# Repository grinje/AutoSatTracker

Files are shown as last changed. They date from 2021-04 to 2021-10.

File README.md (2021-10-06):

# AutoSatTracker-ESP32
Tracking satellites with custom hardware based on stepper motors. A blog description of the project can be found at https://www.la3t.no/automatic-satellite-tracker/

The construction of the rotator is based on the SatNOGS project found here: https://gitlab.com/librespacefoundation/satnogs/satnogs-rotator/tree/master

The controller is based on the work by Elwood Downey found here: http://clearskyinstitute.com/ham/AST/. 
The software is based on this repo by Bjoern Kerler: https://github.com/bkerler/AutoSatTracker-ESP

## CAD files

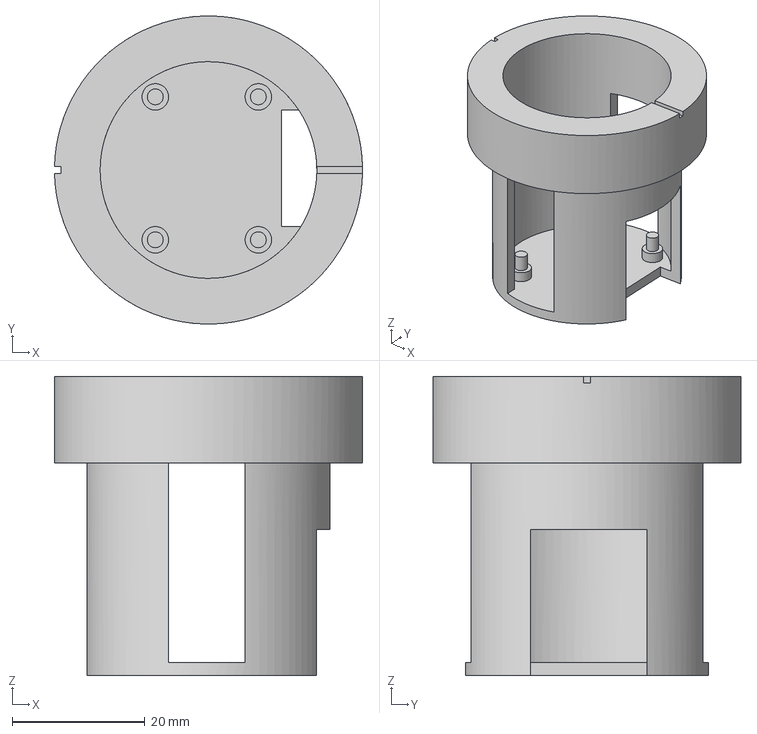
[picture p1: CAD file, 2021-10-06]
Fusion360-CADfiles/CompassHolder v4.3mf
46.3 x 46.3 x 45.0 mm

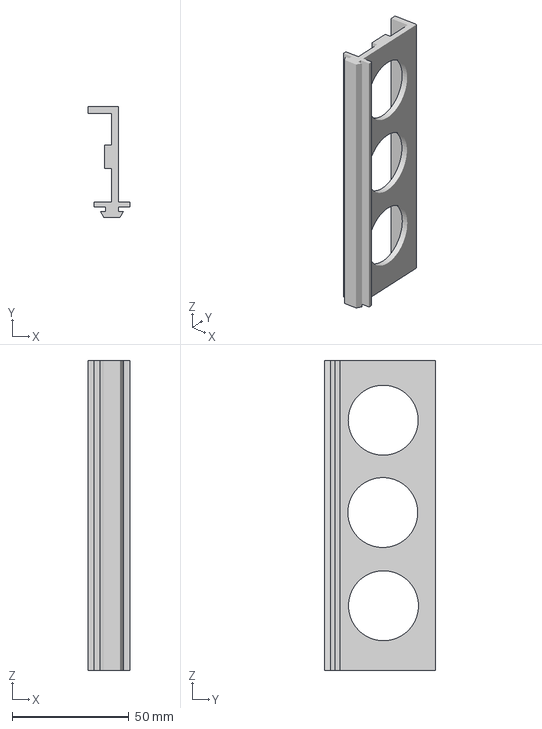
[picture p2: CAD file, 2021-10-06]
Fusion360-CADfiles/Battery Holder v2.3mf
18.0 x 47.5 x 133.0 mm

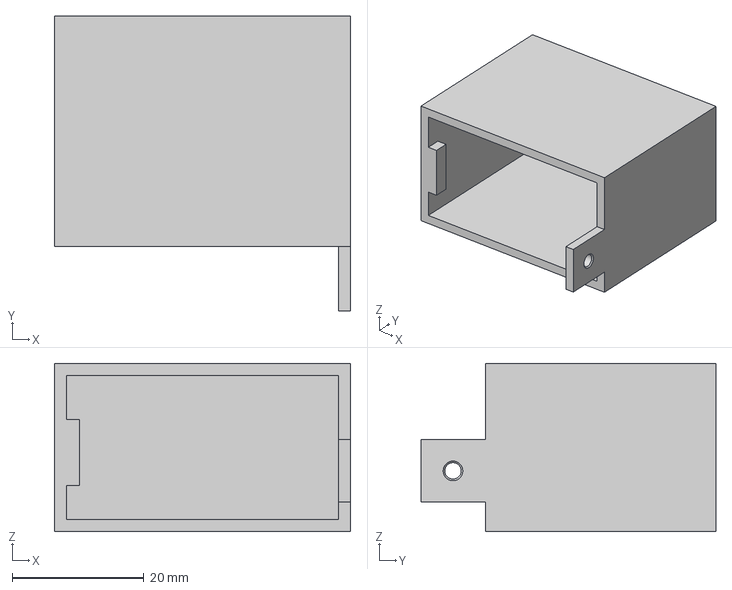
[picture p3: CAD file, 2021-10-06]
Fusion360-CADfiles/Antenna-mount Cap v8.3mf
45.0 x 44.8 x 25.6 mm

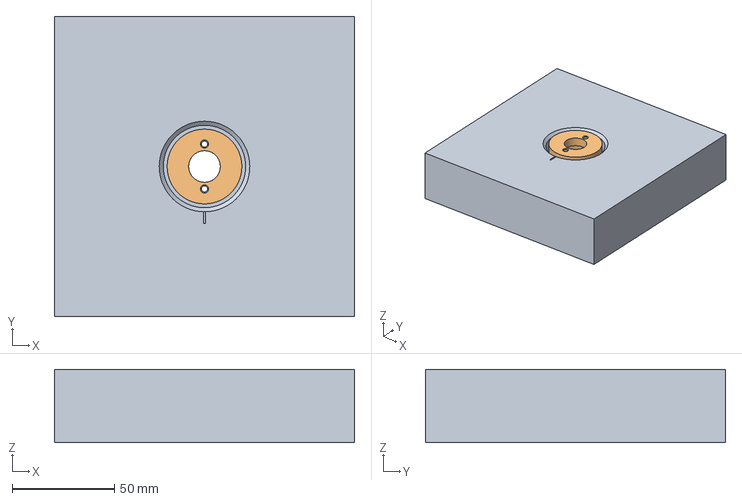
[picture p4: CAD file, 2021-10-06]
Fusion360-CADfiles/TopCover v3.3mf
147.0 x 147.0 x 36.0 mm

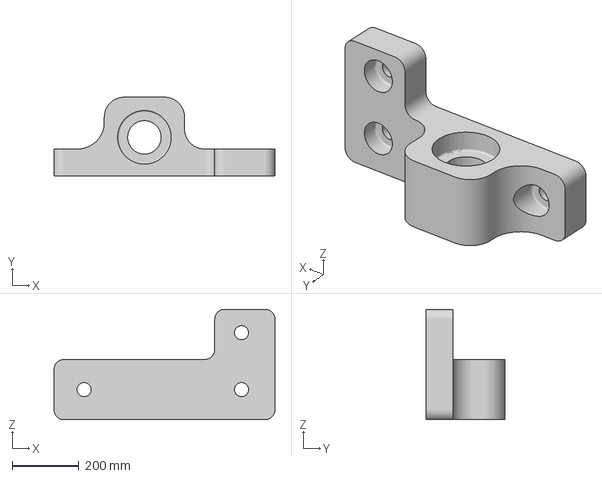
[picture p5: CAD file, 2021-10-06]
Fusion360-CADfiles/C1061-5-GIJ v2.3mf
660.0 x 235.0 x 330.0 mm

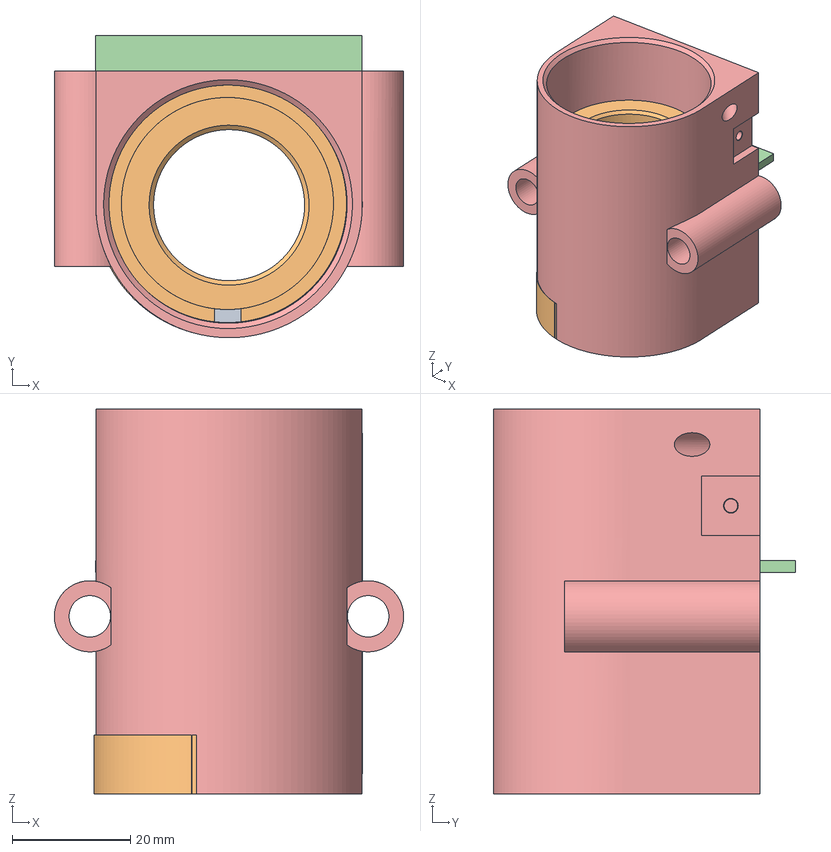
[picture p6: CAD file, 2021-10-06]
Fusion360-CADfiles/Antenna-mount v8.3mf
59.0 x 51.1 x 65.0 mm

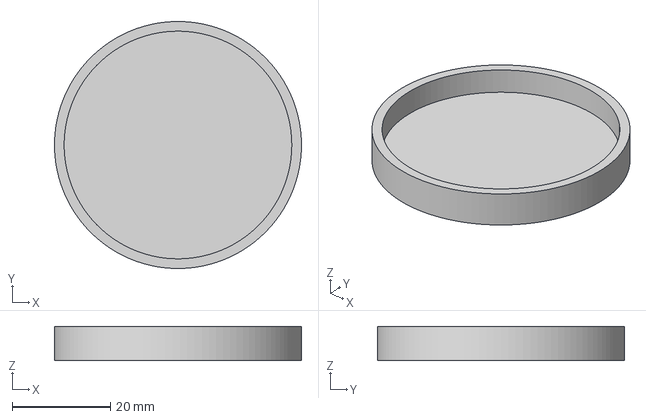
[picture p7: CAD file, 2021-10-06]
Fusion360-CADfiles/CompassCover v1.3mf
50.3 x 50.3 x 7.00 mm

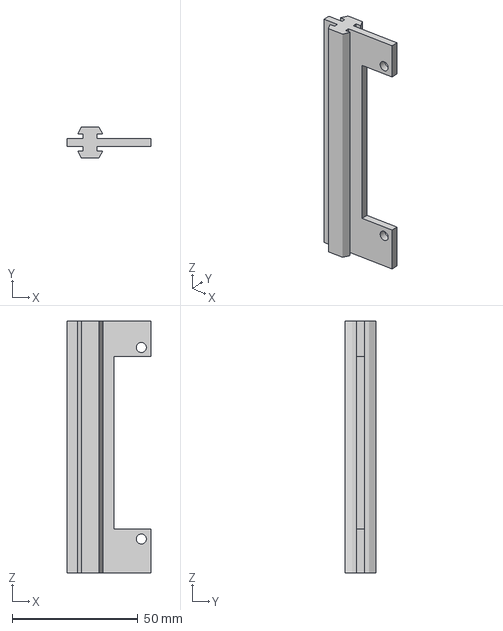
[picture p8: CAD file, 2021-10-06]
Fusion360-CADfiles/PCB mount v5.3mf
33.5 x 12.4 x 100.0 mm

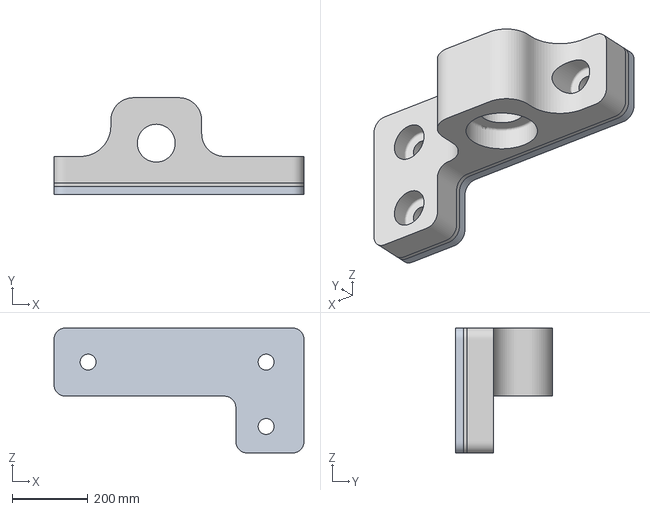
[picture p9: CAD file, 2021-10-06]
Fusion360-CADfiles/C1061-6-GIJ v2.3mf
660.0 x 255.0 x 330.0 mm

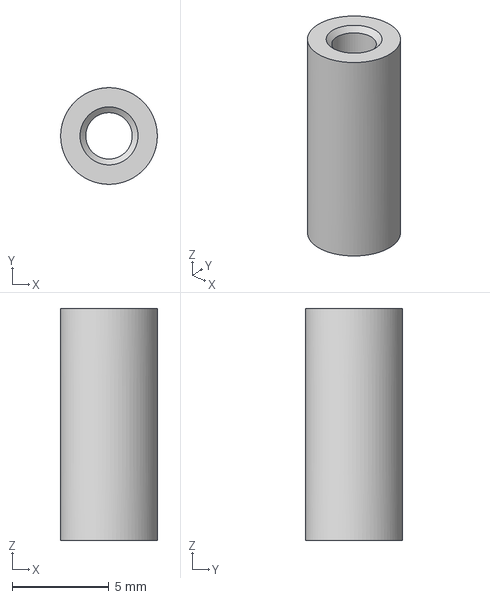
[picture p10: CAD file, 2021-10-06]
Fusion360-CADfiles/GPS-mount-extension v1.3mf
5.00 x 5.00 x 12.0 mm

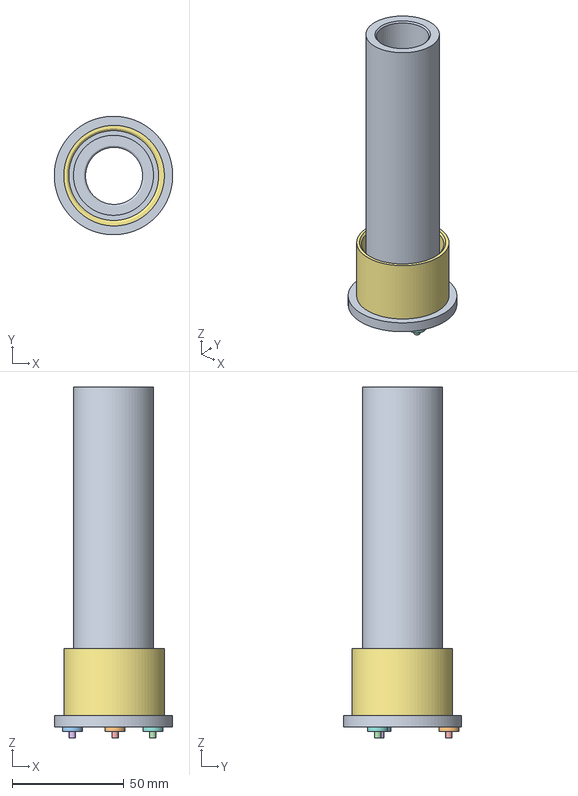
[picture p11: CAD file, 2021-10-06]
Fusion360-CADfiles/Tripod-mount v6.3mf
53.0 x 53.0 x 157.0 mm

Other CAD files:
Fusion360-CADfiles/Antenna-mount v8.f3d
Fusion360-CADfiles/Battery Holder v2.f3d
Fusion360-CADfiles/C1061-5-GIJ v2.f3d
Fusion360-CADfiles/C1061-6-GIJ v2.f3d
Fusion360-CADfiles/CompassCover v1.f3d
Fusion360-CADfiles/CompassHolder v4.f3d
Fusion360-CADfiles/GPS-mount-extension v1.f3d
Fusion360-CADfiles/PCB mount v5.f3d
Fusion360-CADfiles/TopCover v3.f3d
Fusion360-CADfiles/Tripod-mount v6.f3d

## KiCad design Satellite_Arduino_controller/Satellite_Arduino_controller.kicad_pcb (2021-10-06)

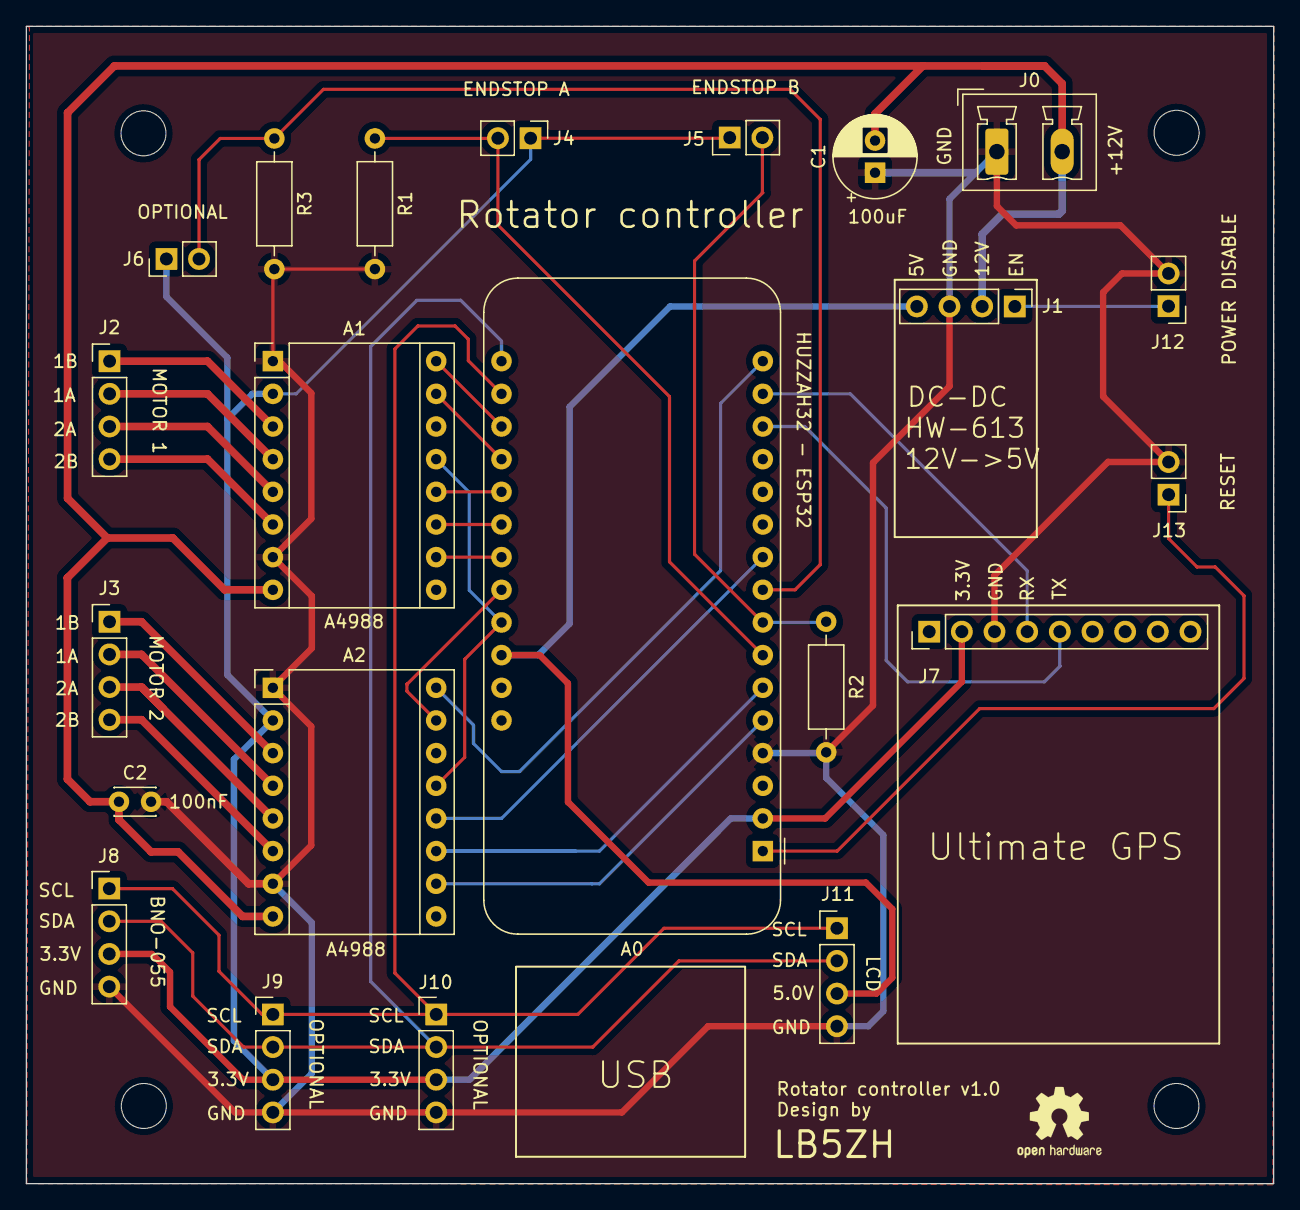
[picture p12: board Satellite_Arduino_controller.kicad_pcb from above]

Board: 2 copper layers, 97.0 x 90.0 mm, 22 parts (0 on the bottom side), 32 nets.

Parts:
A0: Adafruit_Feather_HUZZAH32_ESP32; Adafruit_Feather
A1, A2: A4988; Pololu_Breakout-16_15.2x20.3mm
C1: 100uF; CP_Radial_D6.3mm_P2.50mm
C2: 100nF; C_Disc_D3.0mm_W2.0mm_P2.50mm
J0: Power input; PhoenixContact_MCV_1,5_2-G-5.08_1x02_P5.08mm_Vertical
J1: DC-DC; PinHeader_1x04_P2.54mm_Vertical
J2: Motor 1; PinHeader_1x04_P2.54mm_Vertical
J3: Motor 2; PinHeader_1x04_P2.54mm_Vertical
J4: Endstop A; PinHeader_1x02_P2.54mm_Vertical
J5: Endstop B; PinHeader_1x02_P2.54mm_Vertical
J6: Optional; PinHeader_1x02_P2.54mm_Vertical
J7: Ultimate GPS; PinHeader_1x09_P2.54mm_Vertical
J8: BNO-055; PinHeader_1x04_P2.54mm_Vertical
J9, J10: Optional sensor; PinHeader_1x04_P2.54mm_Vertical
J11: LCD 20x4; PinHeader_1x04_P2.54mm_Vertical
J12: Power disable; PinHeader_1x02_P2.54mm_Vertical
J13: RESET; PinHeader_1x02_P2.54mm_Vertical
R1, R2, R3: 10k; R_Axial_DIN0207_L6.3mm_D2.5mm_P10.16mm_Horizontal

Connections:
+3V3: A0.2 (3V3), A1.2 (VDD), A2.2 (VDD), J4.1, J5.1, J6.1, J7.2, J8.3, J9.3, J10.3
+5V: A0.26 (USB), J1.4, J11.3
+12V: A1.8 (VMOT), A2.8 (VMOT), C1.2, C2.1, J0.2, J1.2
/EN1: J1.1, J12.1
/RX: A0.15 (TX/IO17), J7.4
/SCL: A0.18 (SCL/IO22), J8.1, J9.1, J10.1, J11.1
/SDA: A0.17 (SDA/IO23), J8.2, J9.2, J10.2, J11.2
/TX: A0.14 (RX/IO16), J7.5
GND: A0.4 (GND), A1.1 (GND), A1.7 (GND), A2.1 (GND), A2.7 (GND), C1.1, C2.2, J0.1, J1.3, J7.3, J8.4, J9.4, J10.4, J11.4, J12.2, J13.2, R1.2, R2.2, R3.2
unnamed: A0.1 (~RESET), J13.1
unnamed: A0.5 (DAC2/A0), A2.10 (MS1)
unnamed: A0.6 (DAC1/A1), A2.11 (MS2)
unnamed: A0.7 (I34/A2), J4.2, R1.1
unnamed: A0.8 (I39/A3), J5.2, R2.1
unnamed: A0.9 (IO36/A4), J6.2, R3.1
unnamed: A0.10 (IO4/A5), A2.12 (MS3)
unnamed: A0.16 (IO21), A2.16 (DIR)
unnamed: A0.19 (A6/IO14), A1.16 (DIR)
unnamed: A0.20 (A7/IO32), A1.15 (STEP)
unnamed: A0.21 (A8/IO15), A1.12 (MS3)
unnamed: A0.22 (A9/IO33), A1.11 (MS2)
unnamed: A0.23 (A10/IO27), A1.10 (MS1)
unnamed: A0.24 (A11/IO12), A2.15 (STEP)
unnamed: A0.25 (A12/IO13), A1.13 (~RESET), A2.13 (~RESET)
unnamed: A1.3 (1B), J2.1
unnamed: A1.4 (1A), J2.2
unnamed: A1.5 (2A), J2.3
unnamed: A1.6 (2B), J2.4
unnamed: A2.3 (1B), J3.1
unnamed: A2.4 (1A), J3.2
unnamed: A2.5 (2A), J3.3
unnamed: A2.6 (2B), J3.4

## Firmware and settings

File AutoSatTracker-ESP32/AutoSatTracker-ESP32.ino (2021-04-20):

/* Autonomous Satellite Tracker.
 *
 * Connections on Adafruit ESP8266 Huzzah:
 *   Servo controller connects to SDA and SCL
 *   GPS TX connects to 16, RX to 2
 *
 */

#include "LCDPanel.h"
#include "AutoSatTracker-ESP.h"
#include "NV.h"
#include "Sensor.h"
#include "Circum.h"
#include "Stepper.h"
#include "Target.h"
#include "Webpage.h"


NV *nv;
Sensor *sensor;
Circum *circum;
//Gimbal *gimbal;
StepController *stepper;
Target *target;
Webpage *webpage;
LCDPanel *lcd;


/* called first and once
 */
void
setup()
{
  // init serial monitor
  Serial.begin (115200);
  delay(500);

  // init LCD screen
  lcd = new LCDPanel();

  // this just resets the soft timeout, the hard timeout is still 6 seconds
  //ESP.wdtDisable();

  // scan for I2C devices
  resetWatchdog();
  Serial.println();
  lcd->status("Scanning I2C");
   
  Serial.print (F("...Scanning I2C:"));
  for (uint8_t a = 1; a < 127; a++) {
	  Wire.beginTransmission(a);
	  if (Wire.endTransmission() == 0) {
	    Serial.print (' '); Serial.print (a, HEX);
	  }
  }
  
  Serial.println();

  // instantiate each module
  Serial.println (F("making NV"));
  nv = new NV();
  Serial.println (F("making Sensor"));
  lcd->gyro("9DOF      ");

  sensor = new Sensor();
  Serial.println (F("making Circum"));
  lcd->gps("NO GPS");

    circum = new Circum();
    Serial.println (F("making StepController")); 
    stepper = new StepController();
    Serial.println (F("making Target"));
    target = new Target();
    Serial.println (F("making Webpage"));
    webpage = new Webpage();

    // all set to go.. see you in loop()
    Serial.println (F("Ready"));

}

/* called repeatedly forever
 */
void loop()
{   
    // check for ethernet activity
    webpage->checkEthernet();

    // check for new GPS info
    circum->checkGPS();

    // print out Sensor values on LCD
    sensor->printLCD();

    // follow the target
    target->track();
    delay(1);
}

void
resetWatchdog()
{
    //ESP.wdtFeed();
    yield();
}

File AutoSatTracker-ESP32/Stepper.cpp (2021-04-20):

// class to control two motors to track a target az and el using the A4988 stepper contoller
#include "Stepper.h"

void StepController::speed_Full(uint8_t motn) { digitalWrite(motor[motn].MS1Pin, LOW); digitalWrite(motor[motn].MS2Pin, LOW); digitalWrite(motor[motn].MS3Pin, LOW); }
void StepController::speed_Half(uint8_t motn) { digitalWrite(motor[motn].MS1Pin, HIGH); digitalWrite(motor[motn].MS2Pin, LOW); digitalWrite(motor[motn].MS3Pin, LOW); }
void StepController::speed_Quarter(uint8_t motn) { digitalWrite(motor[motn].MS1Pin, LOW); digitalWrite(motor[motn].MS2Pin, HIGH); digitalWrite(motor[motn].MS3Pin, LOW); }
void StepController::speed_Eight(uint8_t motn) { digitalWrite(motor[motn].MS1Pin, HIGH); digitalWrite(motor[motn].MS2Pin, HIGH); digitalWrite(motor[motn].MS3Pin, LOW); }
void StepController::speed_Sixteenth(uint8_t motn) { digitalWrite(motor[motn].MS1Pin, HIGH); digitalWrite(motor[motn].MS2Pin, HIGH); digitalWrite(motor[motn].MS3Pin, HIGH); }

boolean StepController::endstopPressed() {
  resetWatchdog();

  // Are we using physical endstop switches?
  if (endstopSwitches) {
    if (!digitalRead(endstopA)) {
       // Serial.println("Endstop A");
       // Serial.println(endstopA);
        delayMicroseconds(stepDelay);
        return true;
      }

      if (!digitalRead(endstopB)) {
      //  Serial.println("Endstop B");
      //   Serial.println(endstopB);
      delayMicroseconds(stepDelay);
      return true;
    }
    return false;
  }

  // only check at some given time interval
  uint32_t now = millis();
  if (now - last_sensorread < (UPD_PERIOD * 3))
      return false;
      
  last_sensorread = now;

  // Turn off our motors that act as huge magnets
  digitalWrite(enableMotor, LOW);
  delay(1);
  
  // read current sensor direction
  float azimuth, elevation;
  sensor->getAzEl (&azimuth, &elevation);  

  // Remember to enable our motors again
  digitalWrite(enableMotor, HIGH);
  delay(1);

  // Are we hitting our virtual azimuth endstop?
  if ((prevsensor_az > 300 && azimuth < 50) || (prevsensor_az < 50 && azimuth > 300)) {
    Serial.print("Hitting North Azimuth endstop!");Serial.print(prevsensor_az, 4);Serial.print(" "); Serial.println(azimuth);
    delay(500);
    return true;
  }
  Serial.print("Prev: ");Serial.print(prevsensor_az, 4); Serial.print(" Now: "); Serial.println(azimuth, 4);

  prevsensor_az = azimuth;

  // Or are we hitting our virtual elevation switch?
  //Serial.print("Elevation: "); Serial.println(elevation);
  if (elevation < -5 || elevation > 75) {
    return true;
  }

  // No endstop, keep turning
  return false;
}

void StepController::gotoMin(uint8_t motn)
{
  int i = 0;
  
  // set motor direction
  Serial.print("Setting pin HIGH: "); Serial.println(motor[motn].dirPin);
  digitalWrite(motor[motn].dirPin, HIGH);

  // set speed
  speed_Half(motn);

  // enable motor
  digitalWrite(enableMotor, HIGH);

  // Turn until we hit the endstop
  while (!endstopPressed()) {
    resetWatchdog();
   // Serial.print(motn);Serial.print(" FORWARD ");
    //Serial.println(motor[motn].stepPin);
    digitalWrite(motor[motn].stepPin, HIGH);
    delayMicroseconds(stepDelay);
    digitalWrite(motor[motn].stepPin, LOW);
    delayMicroseconds(stepDelay);
  }

  // Lets move out of endstop
  Serial.print("Setting pin LOW: "); Serial.println(motor[motn].dirPin);
  digitalWrite(motor[motn].dirPin, LOW);
  digitalWrite(enableMotor, LOW);delay(UPD_PERIOD * 3);digitalWrite(enableMotor, HIGH);
  while (endstopPressed()) {
    resetWatchdog();
   // Serial.print(motn);Serial.print(" BACKWARD ");
   // Serial.println(motor[motn].stepPin);
   for (i = 0; i < 100; i++) {
    digitalWrite(motor[motn].stepPin, HIGH);
    delayMicroseconds(stepDelay);
    digitalWrite(motor[motn].stepPin, LOW);
    delayMicroseconds(stepDelay);
   }
   digitalWrite(enableMotor, LOW);delay(UPD_PERIOD * 3);digitalWrite(enableMotor, HIGH);
  } 
  // Lets move a safe distance from the endstop (so not to influnce the other axis when testing that)
  for (i = 0; i < 500; i++) {
    digitalWrite(motor[motn].stepPin, HIGH);
    delayMicroseconds(stepDelay);
    digitalWrite(motor[motn].stepPin, LOW);
    delayMicroseconds(stepDelay);
   }

  // disable motor
  digitalWrite(enableMotor, LOW);

}

void StepController::runStepMotor(uint8_t motn, int steps)
{
  /*
   * AZ: HIGH turning left, atmax on left side 
   * EL: HIHG turning down
   */
  bool direction = (steps >= 0 ? LOW : HIGH);
  Serial.print("Motor: "); Serial.print(motn); Serial.print("\tSteps: ");Serial.print(steps);Serial.print(" Direction: "); Serial.println(direction);
  steps = abs(steps);

  // If at end position, just stop turning
/*  if (direction && motor[motn].atmin) {
    Serial.println("At end position, doing nothing");
    return;
  }

  if ((!direction) && motor[motn].atmax) {
    Serial.println("At end of the world, doing nothing");
    return;
  }

  // Reset end signal, as we are moving away
  motor[motn].atmax = false;
  motor[motn].atmin = false;*/
  
  // set motor direction
  digitalWrite(motor[motn].dirPin, direction);
    
  // set speed
  if (steps > 15) 
    speed_Half(motn);
  else
    speed_Quarter(motn);

  // enable motor
  digitalWrite(enableMotor, HIGH);
  delayMicroseconds(stepDelay);

  // Turn the number of steps

  while (steps--) {
    resetWatchdog();
    digitalWrite(motor[motn].stepPin, HIGH);
    delayMicroseconds(stepDelay);
    digitalWrite(motor[motn].stepPin, LOW);
    delayMicroseconds(stepDelay);
    
    if (endstopPressed()) {
      Serial.println("Reached the endstop! Turning back.");
      // Bummer, we reached a full turn. Lets move out of endstop
      digitalWrite(motor[motn].dirPin, !direction);
      speed_Half(motn);
      while (endstopPressed()) {
        resetWatchdog();
        digitalWrite(motor[motn].stepPin, HIGH);
        delayMicroseconds(stepDelay);
        digitalWrite(motor[motn].stepPin, LOW);
        delayMicroseconds(stepDelay);
      } 
      
      if (!direction)
        motor[motn].atmax = true;
      else
        motor[motn].atmin = true;
        
      // disable motor
      digitalWrite(enableMotor, LOW);
      return;
    }
  }

  // disable motor
  digitalWrite(enableMotor, LOW);
}

// An attempt to calibrate the magnetometer
void StepController::goFullTurn()
{
  gotoMin(1);
  runStepMotor(1, -50000);
  gotoMin(1); 
  runStepMotor(1, -50000);
  gotoMin(1); 
}
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

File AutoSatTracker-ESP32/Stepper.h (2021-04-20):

// class to control two motors to track a target az and el using the A4988 stepper controller

#ifndef _STEPPER_H
#define _STEPPER_H

#include <Wire.h>
#include <WiFiClient.h>

#include "AutoSatTracker-ESP.h"
#include "Target.h"
#include "Sensor.h"

class StepController {

    private:

      // Define pin connections & motor's steps per revolution
      // Stepper motor A 
      static const uint8_t dirPinA = 14; // Direction of step
      static const uint8_t stepPinA = 32; // Initiate a step
      static const uint8_t speedA_MS1 = 27; // MS1
      static const uint8_t speedA_MS2 = 33; // MS2
      static const uint8_t speedA_MS3 = 15; // MS3

      // Stepper motor B
      static const uint8_t dirPinB = 21;
      static const uint8_t stepPinB = 12;
      static const uint8_t speedB_MS1 = 26;
      static const uint8_t speedB_MS2 = 25;
      static const uint8_t speedB_MS3 = 4;

      // Connects to the RESET pin 
      static const uint8_t enableMotor = 13; // Enable the step controllers

      // In case you use the endstoppers
      static const uint8_t endstopA = 34;  // End-stop switch for stepper A
      static const uint8_t endstopB = 39;  // End-stop switch for stepper B
      
      boolean stepper_found = 1; // Do we find the stepper motors?
      static const boolean endstopSwitches = false; // We don´t use these switches

      static const int calibrateSteps = 4000; // # Number of steps during calibration

      static const int stepDelay = 1000; // Microseconds to keep the step pin high
 
      // motor info
      typedef struct {
        float az_scale, el_scale;     // az and el scale: steps (del usec) per degree
        uint16_t min, max;        // position limits, usec
        uint16_t pos;       // last commanded position, usec
        int16_t del_pos;        // change in pos since previous move
        bool atmin, atmax;        // (would have been commanded to) limit
        uint8_t step_num;        // Stepper address
        uint8_t dirPin;
        uint8_t stepPin;
        uint8_t MS1Pin;
        uint8_t MS2Pin;
        uint8_t MS3Pin;
      } MotorInfo;
 
      static const uint8_t NMOTORS = 2;   // not easily changed
      MotorInfo motor[NMOTORS];

      // search info
      static const uint16_t UPD_PERIOD = 500;   // ms between updates
      static constexpr float MAX_SETTLE = 2.0;  // considered stopped, degs
      static const uint8_t N_INIT_STEPS = 4;    // number of init_steps
      static constexpr float CAL_FRAC = 0.333;  // fraction of full range to move for calibration
              // N.B.: max physical motion must be < 180/CAL_FRAC

      uint8_t init_step;        // initialization sequencing
      uint8_t best_azmotor;       // after cal, motor[] index with most effect in az
      uint32_t last_update;       // millis() time of last move
      uint32_t last_sensorread;
      float prevfast_az, prevfast_el;     // previous pointing position
      float prevstop_az, prevstop_el;     // previous stopped position
      float prevsensor_az;
      float min_az, min_el;     // endstop positions

      void calibrate (float &az_s, float &el_s);
      void seekTarget (float& az_t, float& el_t, float& az_s, float& el_s);
      float azDist (float &from, float &to);
      float moveDist (float &from, float &to);
      float moveAbs0 (float &from, float &to);

      void speed_Full(uint8_t motn);
      void speed_Half(uint8_t motn);
      void speed_Quarter(uint8_t motn);
      void speed_Eight(uint8_t motn);
      void speed_Sixteenth(uint8_t motn);

      boolean endstopPressed();
      void runStepMotor(uint8_t motn, int steps);
      void gotoMin(uint8_t motn);

  
    public:

      StepController();
      void goFullTurn();
      void moveToAzEl (float az_t, float el_t);
      void sendNewValues (WiFiClient client);
      bool connected() { return stepper_found; };
      bool calibrated() { return (init_step >= N_INIT_STEPS); }
};

extern StepController *stepper;

#endif // _STEPPER_H

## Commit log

2021-10-06 Added schema and pcb
    [Satellite_Arduino_controller.kicad_pcb, Satellite_Arduino_controller.kicad_sch]
2021-10-06 Added CAD files
    [Antenna-mount Cap v8.3mf, Antenna-mount v8.3mf, Antenna-mount v8.f3d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]
